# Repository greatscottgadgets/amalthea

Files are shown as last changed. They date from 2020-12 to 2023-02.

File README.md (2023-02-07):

# Amalthea

This repository contains hardware, gateware, and host software sources for Amalthea - an experimental SDR platform.
The main components of the Amalthea hardware are a Lattice ECP5 FPGA, an AT86RF215 radio transceiver, and a Microchip USB3343 USB2.0 PHY (for use with [LUNA](https://luna.readthedocs.io/)).

## Install

 * Clone and install:

```
git clone https://github.com/greatscottgadgets/amalthea
cd amalthea
pip3 install --user --editable '.'
```

 * Add custom block path to `~/.gnuradio/config.conf`:

```
[grc]
local_blocks_path = /path/to/amalthea/amalthea/gnuradio/
```

## Hybrid-SDR

The `amalthea/gnuradio/` directory contains blocks & example flowgraphs for creating mixed FPGA/SDR designs in GNURadio Companion.

### Blocks

 * `hybridsdr.domain.yml` - This defines the `hybridsdr` IO port domain and how connections are made between `hybridsdr` ports.
 * `amalthea_device.block.yml` - This defines the Amalthea Device block, which represents overall device. This block handles gateware elaboration, build, and programming. It will also handle streaming data to/from the host over USB in later versions.
 * `{amalthea_rx,amalthea_demod}.block.yml` - These define some HybridSDR blocks, which represent DSP blocks that run on the FPGA itself. When instantiated, these are added as submodules to the overall Amaranth design.

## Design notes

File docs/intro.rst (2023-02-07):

Introduction
============

HybridSDR is a toolkit for building software-defined radio systems containing a mixture of software running on a general-purpose computer and gateware running an an FPGA. It allows the user to connect signal processing blocks graphically. Then, at runtime, the gateware design is assembled using the flexibility of `Amaranth <https://github.com/amaranth-lang/amaranth>`_. 

Crossings between the gateware and software domains are handled seamlessly. At runtime a custom USB device is built in gateware using `LUNA <https://github.com/greatscottgadgets/luna>`_.

The current proof-of-concept is provided as an out-of-tree module for `GNU Radio <https://www.gnuradio.org>`_, which includes a graphical interface to place & connect signal processing blocks and a large range of existing blocks to use. It targets the ECP5 FPGA on the `Amalthea <https://github.com/greatscottgadgets/amalthea/>`_ open-source radio platform.

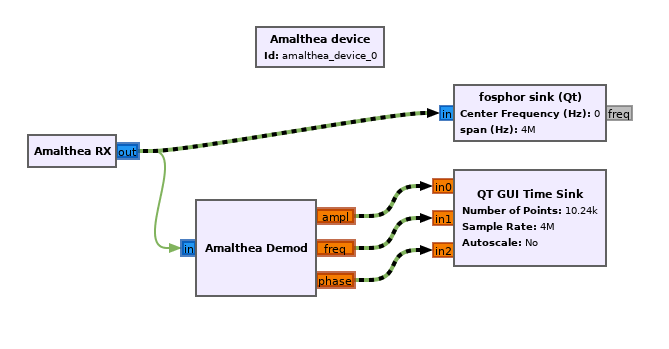
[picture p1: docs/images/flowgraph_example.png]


Above is a screenshot from GNU Radio Companion, showing how the HybridSDR blocks can be used. Green lines represent connections in the gateware domain - these connections and blocks are built into a gateware bitstream at runtime. Green/black striped lines represent seamless connections across USB streams.

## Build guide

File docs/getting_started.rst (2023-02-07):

Getting started
===============

Installation
------------

Clone and install:

::

  git clone https://github.com/greatscottgadgets/amalthea
  cd amalthea
  pip3 install --user --editable '.'

Add custom block path to ~/.gnuradio/config.conf:

::

  [grc]
  local_blocks_path = /path/to/amalthea/amalthea/gnuradio/

Usage
-----

An example flowgraph is provided here: https://github.com/greatscottgadgets/amalthea/blob/master/amalthea/gnuradio/example/hybridsdr.grc

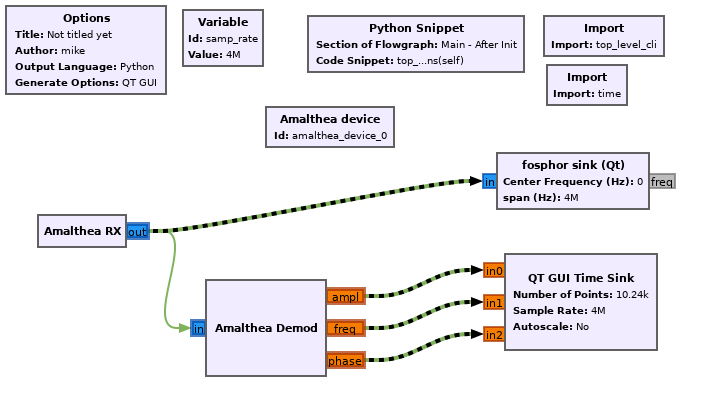
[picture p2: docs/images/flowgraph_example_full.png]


Block details
-------------

Device block
^^^^^^^^^^^^

The HybridSDR device block (`Amalthea device` in this example) represents the external FPGA device and would contain parameters for configuring it/connecting to it. It contains the top-level Amaranth design, the callbacks for registering blocks/connections, and handles the host-side USB streaming when the flowgraph runs.

HybridSDR domain
^^^^^^^^^^^^^^^^

GNU Radio defines the concept of a `sample domain` and allows block inputs/outputs to be placed in a particular domain when they are defined. Here we define a custom `hybridsdr` domain for our FPGA-targeted blocks:

::

  id: hybridsdr
  label: HybridSDR
  color: "#81b35d"
  
  multiple_connections_per_input: false
  multiple_connections_per_output: true
  
  templates:
  -   type: [hybridsdr, hybridsdr]
      connect: self.amalthea_device.connect(("${ source.parent_block.name }", ${ source.key }), ("${ sink.parent_block.name }", ${ sink.key }))
  -   type: [hybridsdr, stream]
      connect: self.amalthea_device.connect_usb(("${ source.parent_block.name }", ${ source.key }), ${ make_port_sig(sink) })
  
This also defines how connections should be made between different domains:
 - Connections between two `hybridsdr` ports are registered with the `Device block`.
 - Connections between `hybridsdr` and `stream` (GNU Radio's standard sample domain) represent a crossing from the FPGA device to the host PC, and have a special callback that will create a seamless USB stream during elaboration.

Gateware blocks
^^^^^^^^^^^^^^^

These are blocks that represent functionality targeted at the FPGA. Here, `Amalthea RX` represents the radio receiver on the Amalthea device and is a source of samples. `Amalthea Demod` represents an Amaranth HDL module implementing amplitude, frequency, and phase demodulation.

Blocks are implemented as standard Amaranth HDL modules, using Amaranth/LUNA stream interfaces for input and output. Blocks are defined and exposed to GNU Radio Companion using standard GNU Radio YAML configuration files. This configuration includes a template for instantiation which registers the block with the `Device block`:

::

  id: amalthea_demod
  label: Amalthea Demod
  category: '[Amalthea]'
  
  templates:
    imports: |-
        import amalthea
    make: |
        self.amalthea_device.add_block("${id}", amalthea.gateware.demod.CORDICDemod(13))

Block inputs and outputs are created within the `hybridsdr` domain:

::

  inputs:
  - domain: hybridsdr
    dtype: complex
    vlen: 1
  
  outputs:
  - domain: hybridsdr
    label: ampl
    dtype: float
    optional: true
  - domain: hybridsdr
    label: freq
    dtype: float
    optional: true
  - domain: hybridsdr
    label: phase
    dtype: float
    optional: true
  
Extras
^^^^^^

GNU Radio doesn't currently have a way for the device block to run code just before the flowgraph starts, so the gateware build/program step is invoked using a `Python Snippet` block in this example:

::

  top_level_cli(self.amalthea_device)
  time.sleep(10)
  self.amalthea_device.finalize_usb_connections(self)

This builds the gatware and programs the Amalthea device, waits for it to start & enumerate, then creates the host-side USB connections to the `stream`-domain blocks.

Other buses
-----------

By default, HybridSDR designs use Amaranth/LUNA stream interfaces between blocks. However, by using the same techniques above to design custom sample domains & connection behaviour, other bus standards can be supported and interconnected.

An example block implementing a pipelined Wishbone interface is included. The domain definition includes a template for inserting an adapter module so that it can interface with the LUNA USB stream interface:

::

  templates:
  -   type: [wishbone, stream]
      connect: |-
          self.${source.parent_block.name}_stream = amalthea.gateware.wishbone_example.StreamAdapter(self.${source.parent_block.name})
          self.amalthea_device.add_block("${source.parent_block.name}_stream", self.${source.parent_block.name}_stream)
          self.amalthea_device.connect_usb(("${ source.parent_block.name }_stream", ${ source.key }), ${ make_port_sig(sink) })

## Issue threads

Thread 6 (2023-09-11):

What happened to this project?

Hoernchen, 2023-09-11:
I have just discovered this and it kinda looks like a great fgpa/atrf dev board - after browsing twitter for a bit it looks like at least iq rx streaming to GR/fossphor was actually validated with real hardware, are there any known issues? I guess this project, just like so many other projects, just stalled due to part shortages?

mossmann, 2023-09-12:
The project is still progressing slowly. The current incarnation of hardware is a small add-on for Cynthion: https://github.com/greatscottgadgets/amalthea-hardware

@mndza has been working on DSP gateware here: https://github.com/mndza/dsp_sandbox

Closed 2023-11-06.

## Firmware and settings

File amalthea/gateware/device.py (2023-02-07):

#!/usr/bin/env python3
# pylint: disable=no-member

import os
import sys
import logging
import time
import usb1
import xdg.BaseDirectory

import numpy as np

from amaranth                        import *
from amaranth.lib.fifo               import AsyncFIFO
from amaranth.build.run              import LocalBuildProducts

from usb_protocol.types              import USBRequestType
from usb_protocol.emitters           import DeviceDescriptorCollection

from luna                            import top_level_cli
from luna.usb2                       import *
from luna.gateware.usb.usb2.request  import USBRequestHandler
from luna.gateware.platform          import get_appropriate_platform

from .radio                          import IQReceiver, RadioSPI
from .demod                          import CORDICDemod
from .stream                         import IQStream, SampleStream, StreamCombiner

from ..gnuradio.amaltheasource import AmaltheaSource


VENDOR_ID  = 0x16d0
PRODUCT_ID = 0x0f3b

BULK_ENDPOINT_NUMBER = 1
MAX_BULK_PACKET_SIZE = 64 if os.getenv('LUNA_FULL_ONLY') else 512

class RadioSPIRequestHandler(USBRequestHandler):
    """ Read/write radio SPI registers. """

    REQUEST_WRITE_REG = 0

    def __init__(self):
        super(RadioSPIRequestHandler, self).__init__()
        self.spi_start       = Signal()
        self.spi_busy        = Signal()
        self.spi_address     = Signal(14)
        self.spi_write       = Signal()
        self.spi_write_value = Signal(8)

    def elaborate(self, platform):
        m = Module()

        interface         = self.interface
        setup             = self.interface.setup

        m.d.comb += self.spi_write.eq(1) # Only support writes for now
        m.d.sync += self.spi_start.eq(0)

        with m.If(setup.type == USBRequestType.VENDOR):
            with m.FSM():
                with m.State('IDLE'):
                    with m.If(setup.received):
                        with m.Switch(setup.request):
                            with m.Case(self.REQUEST_WRITE_REG):
                                m.d.sync += [
                                    self.spi_address.eq(setup.index[:14]),
                                    self.spi_write_value.eq(setup.value[:8]),
                                    self.spi_start.eq(1),
                                ],
                                m.next = 'WRITE_REG'

                            with m.Default():
                                m.next = 'UNHANDLED'

                with m.State('WRITE_REG'):
                    # Once the receive is complete, respond with an ACK.
                    with m.If(interface.rx_ready_for_response):
                        m.d.comb += interface.handshakes_out.ack.eq(1)

                    # If we reach the status stage, send a ZLP.
                    with m.If(interface.status_requested):
                        m.d.comb += self.send_zlp()
                        m.next = 'IDLE'


                with m.State('UNHANDLED'):

                    #
                    # Stall unhandled requests.
                    #
                    with m.If(interface.status_requested | interface.data_requested):
                        m.d.comb += interface.handshakes_out.stall.eq(1)
                        m.next = 'IDLE'

                return m


class Device(Elaboratable):
    """ Amalthea device. """

    def __init__(self):
        self._rx = IQReceiver();
        self._blocks = {}
        self._usb_outputs = []
        self._connections = []
        self._usb_connections = []

    def get_rx(self):
        return self._rx

    def add_block(self, block_id, block):
        self._blocks[block_id] = block
        return block

    def connect(self, source, sink):
        print(f"connect {source} {sink}")
        source_id, source_output = source
        sink_id, sink_input = sink

        source_block = self._blocks[source_id]
        sink_block   = self._blocks[sink_id]
        self._connections.append(sink_block.input.stream_eq(source_block.outputs[source_output]))

    def connect_usb(self, source, sink):
        print(f"connect_usb {source}")
        block_id, output_id = source
        self._usb_outputs.append(self._blocks[block_id].outputs[output_id])
        self._usb_connections.append((len(self._usb_outputs)-1, sink))

    def flash(self):
        platform = get_appropriate_platform()
        plan = platform.build(self, do_build=False)
        cache_dir = os.path.join(
            xdg.BaseDirectory.save_cache_path('amalthea'),
            'build',
            plan.digest().hex()
        )
        if os.path.exists(cache_dir):
            products = LocalBuildProducts(cache_dir)
        else:
            products = plan.execute_local(cache_dir)

        platform.toolchain_program(products, name="top")

    def finalize_usb_connections(self, tb):
        def to_np_type(output):
            if isinstance(output, IQStream):
                return np.complex64
            if isinstance(output, SampleStream):
                return np.float32
            raise TypeError("Unknown stream type")

        signature = list(map(to_np_type, self._usb_outputs))
        self._usb_source = AmaltheaSource(4e6, 2.45e9, signature)
        for conn in self._usb_connections:
            tb.connect((self._usb_source, conn[0]), conn[1])


    def create_descriptors(self):
        """ Create the descriptors we want to use for our device. """

        descriptors = DeviceDescriptorCollection()

        #
        # We'll add the major components of the descriptors we we want.
        # The collection we build here will be necessary to create a standard endpoint.
        #

        # We'll need a device descriptor...
        with descriptors.DeviceDescriptor() as d:
            d.idVendor           = VENDOR_ID
            d.idProduct          = PRODUCT_ID

            d.iManufacturer      = "GSG"
            d.iProduct           = "Amalthea receiver"
            d.iSerialNumber      = "no serial"

            d.bNumConfigurations = 1


        # ... and a description of the USB configuration we'll provide.
        with descriptors.ConfigurationDescriptor() as c:

            with c.InterfaceDescriptor() as i:
                i.bInterfaceNumber = 0

                with i.EndpointDescriptor() as e:
                    e.bEndpointAddress = 0x80 | BULK_ENDPOINT_NUMBER
                    e.wMaxPacketSize   = MAX_BULK_PACKET_SIZE


        return descriptors


    def elaborate(self, platform):
        m = Module()

        # Generate our domain clocks/resets.
        m.submodules.car = platform.clock_domain_generator()

        # Create our USB device interface...
        ulpi = platform.request("host_phy")
        m.submodules.usb = usb = USBDevice(bus=ulpi)

        # Add our standard control endpoint to the device.
        descriptors = self.create_descriptors()
        control_ep = usb.add_standard_control_endpoint(descriptors)

        # Add our vendor request handler
        handler = DomainRenamer("usb")(RadioSPIRequestHandler())
        control_ep.add_request_handler(handler)

        radio = platform.request("radio")
        m.d.comb += radio.rst.eq(0)

        # Setup the radio SPI interface.
        radio_spi = DomainRenamer("usb")(RadioSPI(clk_freq=60e6))
        m.submodules += radio_spi

        m.d.comb += [
            # Output pins
            radio.sel              .eq(radio_spi.sel),
            radio.clk              .eq(radio_spi.clk),
            radio.copi             .eq(radio_spi.copi),

            # Input pins
            radio_spi.cipo         .eq(radio.cipo),

            # Vendor request handler connections
            radio_spi.start        .eq(handler.spi_start),
            handler.spi_busy       .eq(radio_spi.busy),
            radio_spi.address      .eq(handler.spi_address),
            radio_spi.write        .eq(handler.spi_write),
            radio_spi.write_value  .eq(handler.spi_write_value),
        ]

        # Create radio clock domain
        m.domains.radio = ClockDomain()
        m.d.comb += [
            ClockSignal("radio").eq(radio.rxclk),
            ResetSignal("radio").eq(ResetSignal()),
        ]

        # Get IQ samples.
        iq_rx = self.get_rx()
        m.d.comb += iq_rx.rxd.eq(radio.rxd24)

        #
        m.submodules += map(DomainRenamer("radio"), self._blocks.values())
        m.d.comb += self._connections

        combined = StreamCombiner(
            streams=self._usb_outputs,
            domain="radio",
        )
        m.submodules += combined

        payload = combined.output.payload
        usb_data = Cat(
            # Pad each 13-bit value to 16-bits for now.
            payload.word_select(i, 13).shift_left(3) for i in range(int(len(payload)/13))
        )
        assert (len(usb_data) % 8) == 0, f"{len(usb_data)}"


        # Add a stream endpoint to our device.
        stream_ep = USBMultibyteStreamInEndpoint(
            byte_width=int(len(usb_data)/8),
            endpoint_number=BULK_ENDPOINT_NUMBER,
            max_packet_size=MAX_BULK_PACKET_SIZE
        )
        usb.add_endpoint(stream_ep)

        # Connect our device as a high speed device by default.
        m.d.comb += [
            usb.connect          .eq(1),
            usb.full_speed_only  .eq(1 if os.getenv('LUNA_FULL_ONLY') else 0),
        ]

        # Connect up the IQ receiver to the USB stream, via a small FIFO.
        fifo  = AsyncFIFO(width=len(usb_data), depth=128, r_domain="usb", w_domain="radio")
        m.submodules += fifo
        m.d.comb += [
            combined.output.ready      .eq(fifo.w_rdy),
            fifo.w_en                  .eq(combined.output.valid),
            fifo.w_data                .eq(usb_data),
            fifo.r_en                  .eq(stream_ep.stream.ready),
            stream_ep.stream.valid     .eq(fifo.r_rdy),
            stream_ep.stream.payload   .eq(fifo.r_data),
            stream_ep.stream.last      .eq(0),
        ]

        # Debug LEDs.
        led0 = platform.request("led", 0)
        m.d.radio += led0.eq(iq_rx.outputs[0].valid)
        led1 = platform.request("led", 1)
        m.d.usb += led1.eq(stream_ep.stream.valid)
        led2 = platform.request("led", 2)
        m.d.radio += led2.eq(fifo.w_rdy)


        return m


if __name__ == "__main__":
    device = top_level_cli(Device)

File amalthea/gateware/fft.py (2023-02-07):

from amaranth import *
from amaranth.hdl.dsl import _ModuleBuilderSubmodules
from amaranth.sim import Simulator, Settle
from .types.complex import Complex, ComplexConst
from .types.fixed_point import Q
from .util import variable_rotate_left
import cmath
import math
import numpy as np
import unittest


class FFT(Elaboratable):
    def __init__(self, fft_size, sample_shape):
        self.fft_size = fft_size
        levels = math.log2(fft_size)
        assert levels.is_integer()
        self.level_count = int(levels)
        self.butterfly_count = int(fft_size / 2)

        self.sample_shape = sample_shape
        self.internal_shape = Q(sample_shape.integer_bits + self.level_count, sample_shape.fraction_bits)
        self.twiddle_factor_shape = Q(1, len(self.internal_shape)-1)

        self.mem = Memory(width=len(Complex(shape=self.internal_shape).value()), depth=fft_size)
        self.read_addr = Signal(range(fft_size))
        self.read_data = Signal(self.mem.width)

        self.start = Signal()
        self.done = Signal()

        self._addr_gen = AddressGenerator(self.level_count, self.butterfly_count)
        self._butterfly = Butterfly(self.internal_shape, self.twiddle_factor_shape)

    def elaborate(self, platform):
        m = Module()

        next_address = Signal()
        reset = Signal()

        m.submodules.addr_gen = ResetInserter(reset)(
            EnableInserter(next_address)(
                self._addr_gen
            )
        )

        m.submodules.butterfly = self._butterfly
        m.submodules.twiddle_factors = twiddle_factors = TwiddleFactors(self.fft_size, self.twiddle_factor_shape)

        m.submodules.read_a = read_a = self.mem.read_port(transparent=False)
        m.submodules.read_b = read_b = self.mem.read_port(transparent=False)
        m.submodules.write_a = write_a = self.mem.write_port()
        m.submodules.write_b = write_b = self.mem.write_port()
        m.d.comb += [
            # Addresses
            read_a.addr.eq(Mux(self.done, self.read_addr, self._addr_gen.addr_a)),
            read_b.addr.eq(self._addr_gen.addr_b),
            write_a.addr.eq(self._addr_gen.addr_a),
            write_b.addr.eq(self._addr_gen.addr_b),
            twiddle_factors.addr.eq(self._addr_gen.addr_twiddle),

            # Data reads
            self._butterfly.in_a.value().eq(read_a.data),
            self._butterfly.in_b.value().eq(read_b.data),
            self._butterfly.twiddle_factor.eq(twiddle_factors.out),
            self.read_data.eq(read_a.data),

            # Data writes
            write_a.data.eq(self._butterfly.out_a.value()),
            write_b.data.eq(self._butterfly.out_b.value()),
        ]
        with m.FSM() as fsm:
            with m.State("IDLE"):
                m.d.comb += [
                    reset.eq(1),
                    self.done.eq(1),
                ]
                with m.If(self.start):
                    m.next = "READ"

            with m.State("READ"):
                m.d.comb += [
                    read_a.en.eq(1),
                    read_b.en.eq(1),
                ]
                m.next = "WAIT"
                with m.If(self._addr_gen.done):
                    m.next = "IDLE"

            with m.State("WAIT"):
                m.next = "WRITE"

            with m.State("WRITE"):
                m.d.comb += [
                    write_a.en.eq(1),
                    write_b.en.eq(1),
                    next_address.eq(1),
                ]
                m.next = "READ"


        return m


class AddressGenerator(Elaboratable):
    def __init__(self, level_count, butterfly_count):
        self.level_count = level_count
        self.butterfly_count = butterfly_count

        self.done         = Signal()
        self.addr_a       = Signal(range(butterfly_count*2))
        self.addr_b       = Signal(range(butterfly_count*2))
        self.addr_twiddle = Signal(range(butterfly_count))

    def elaborate(self, platform):
        m = Module()

        level        = Signal(range(self.level_count))
        index        = Signal(range(self.butterfly_count))
        twiddle_mask = Signal.like(index)

        final_level = (level == self.level_count - 1)
        next_level  = (index == self.butterfly_count - 1)


        with m.If(next_level):
            m.d.sync += [
                level.eq(level + 1),
                index.eq(0),
                twiddle_mask.eq(Cat(twiddle_mask[1:], 1)),
            ]
            with m.If(final_level):
                m.d.sync += self.done.eq(1)

        with m.Else():
            m.d.sync += [
                index.eq(index + 1),
            ]

        addr_a = (index << 1)
        addr_b = addr_a + 1

        addr_a = variable_rotate_left(addr_a[:self.level_count], level)
        addr_b = variable_rotate_left(addr_b[:self.level_count], level)

        m.d.comb += [
            self.addr_a.eq(addr_a),
            self.addr_b.eq(addr_b),
            self.addr_twiddle.eq(index & twiddle_mask),
        ]

        return m


class Butterfly(Elaboratable):
    def __init__(self, sample_shape, twiddle_factor_shape):
        self.sample_shape   = sample_shape
        self.in_a           = Complex(shape=sample_shape)
        self.in_b           = Complex(shape=sample_shape)
        self.out_a          = Complex(shape=sample_shape)
        self.out_b          = Complex(shape=sample_shape)
        self.twiddle_factor = Complex(shape=twiddle_factor_shape)

    def elaborate(self, platform):
        m = Module()

        a = self.in_a
        b = self.in_b * self.twiddle_factor
        b = b.reshape(self.sample_shape)
        m.d.comb += [
            self.out_a.eq((a + b).reshape(self.sample_shape)),
            self.out_b.eq((a - b).reshape(self.sample_shape)),
        ]

        return m


class TwiddleFactors(Elaboratable):
    def __init__(self, fft_size, sample_shape):
        self.fft_size = fft_size

        tf_count = int(fft_size/2)

        def tf(k):
            tf = cmath.exp(-1j * math.tau * k / fft_size)
            m = 2**sample_shape.fraction_bits - 1
            return (round(tf.real*m), round(tf.imag*m))

        twiddle_factors = [tf(k) for k in range(tf_count)]
        tf_real = [x[0] for x in twiddle_factors]
        tf_imag = [x[1] for x in twiddle_factors]
        self.mem_real = Memory(width=len(sample_shape), depth=len(twiddle_factors), init=tf_real)
        self.mem_imag = Memory(width=len(sample_shape), depth=len(twiddle_factors), init=tf_imag)
        self.out   = Complex(shape=sample_shape)
        self.addr  = Signal(range(tf_count))


    def elaborate(self, platform):
        m = Module()
        m.submodules.rd_real = rd_real = self.mem_real.read_port()
        m.submodules.rd_imag = rd_imag = self.mem_imag.read_port()
        m.d.comb += [
            rd_real.addr.eq(self.addr),
            rd_imag.addr.eq(self.addr),
            self.out.real.eq(rd_real.data),
            self.out.imag.eq(rd_imag.data),
        ]
        return m
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

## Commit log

2020-03-25 Start with LUNA
    [debug_control_connections.sch, fpga_configuration.sch, host_side.sch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]
2020-03-25 Bulk rename
    [amalthea_rev0.kicad_pcb, amalthea_rev0.sch, debug_control_connections.sch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]
2020-03-30 Update license
    [amalthea_rev0.sch, debug_control_connections.sch, fpga_configuration.sch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]
2020-03-30 Remove target PHY
    [amalthea_rev0.sch, target_side.sch]
2020-03-30 Add AT86RF215 & some schematic hookup
    [target_side.sch]
2020-03-30 More tidying
    [amalthea_rev0.kicad_pcb]
2020-03-31 Rough out LVDS
    [amalthea_rev0.kicad_pcb, amalthea_rev0.sch, target_side.sch]
2020-04-06 Add baluns, matching, TXCO, decoupling
    [amalthea_rev0.kicad_pcb, amalthea_rev0.sch, target_side.sch]
2020-04-07 Do a bunch of placement
    [amalthea_rev0.kicad_pcb, amalthea_rev0.sch, target_side.sch]
2020-04-08 Start re-arranging user IO
    [amalthea_rev0.kicad_pcb, amalthea_rev0.sch, host_side.sch]
2020-04-08 Switch to 3V3 for RAM, remove 1V8 rail
    [amalthea_rev0.kicad_pcb, fpga_configuration.sch, power_supplies.sch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]
2020-04-08 Route LVDS user IO
    [amalthea_rev0.kicad_pcb, amalthea_rev0.sch, debug_control_connections.sch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]
2020-04-09 Tidy up decoupling & fix a bunch of DRC errors
    [amalthea_rev0.kicad_pcb, power_supplies.sch]
2020-04-09 Route most of the 'RF215
    [amalthea_rev0.kicad_pcb, target_side.sch]
2020-04-13 Route RF bit, finish io0/1, DRC fixups
    [amalthea_rev0.kicad_pcb]
2020-04-14 Fix error in balun footprint & re-route
    [amalthea_rev0.kicad_pcb]
2020-04-14 Fix TCR2EE footprint
    [amalthea_rev0.kicad_pcb, power_supplies.sch]
2020-04-14 Route/NC remaining target signals, ERC & schematic cleanup
    [amalthea_rev0.kicad_pcb, amalthea_rev0.sch, debug_control_connections.sch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]
2020-04-14 Extend RF-side ground pour
    [amalthea_rev0.kicad_pcb]
2020-04-14 Hide component references
    [amalthea_rev0.kicad_pcb]
2020-04-14 Tidy up component values
    [fpga_configuration.sch, host_side.sch, power_supplies.sch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]
2020-04-14 Tidy up RF09_x routing
    [amalthea_rev0.kicad_pcb]
2020-04-14 Tidy up silk
    [amalthea_rev0.kicad_pcb]
2020-04-14 Widen RF diff traces
    [amalthea_rev0.kicad_pcb]
2020-04-14 Rejig user IO
    [amalthea_rev0.kicad_pcb, amalthea_rev0.sch, host_side.sch]
2020-04-19 Pick part numbers for BOM
    [amalthea_rev0.sch, fpga_configuration.sch, host_side.sch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]
2020-04-19 Swap TCXO for one available on Mouser
    [target_side.sch]
2020-04-19 Fix TCR2EE11 MPN
    [power_supplies.sch]
2020-04-20 Swap JTAG connector part
    [fpga_configuration.sch]
2020-04-23 Fix meander
    [amalthea_rev0-B_Cu.gbl, amalthea_rev0-B_Mask.gbs, amalthea_rev0-B_Paste.gbp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]
2020-04-27 Add gateware for radio config over SPI
2020-05-08 gateware.radio: drop SPI freq for interactive test & add sanity asserts
2020-05-08 interactive-test: add radio test-case
2020-05-11 interactive-test: support radio SPI writes
2020-05-15 receiver: add vendor request to write radio SPI registers
2020-05-16 receiver: receive some samples!
2020-05-29 receiver: make it work
    * Only emit a full IQ sample when possible & use Serializer to prep it
    for USB FIFO.
    * Add loop-back mode & TX counter for testing.
2020-07-03 hardware: adopt OSHWA convention for SPI signal names
    https://www.oshwa.org/a-resolution-to-redefine-spi-signal-names
    [amalthea_rev0.kicad_pcb, amalthea_rev0.sch, right_side_indicators.sch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]
2020-07-28 gateware: swap serializer endianness to tidy up `iq_sample` signal
    [util.py]
2020-07-28 gateware: change i/q samples to signed
2020-10-10 gateware: receiver -> device
2020-10-10 gateware.device: Drop old demo code.
2020-10-11 initial flowgraph build support
2020-10-12 gateware.device: drop old TX loopback test code
2020-10-15 gateware: add missing stream.py
    [stream.py]
2020-10-15 gateware.demod: fix overflow due to CORDIC gain
    [demod.py]
2020-10-18 Working block creation/connection & device building from GRC
2020-11-14 gateware.device: fix stream connections for latest LUNA
    See LUNA @ cd40642 for more detail.
    [device.py]
2021-02-17 Poll for device connect after programming
2021-05-31 gateware: convert Complex to use FixedPointValue
    [fft.py]
2021-06-26 gateware.fft: update classes to use fixed-point shapes
    [fft.py]
2021-06-26 gateware.fft: fix twiddle address generation
    [fft.py]
2021-06-26 gateware.fft: fix twiddle factors
    The previous TFs matched those given in the paper
    "The Fast Fourier Transform in Hardware: A Tutorial Based on an FPGA Implementation"
    but the overall FFT results were incorrect (mirrored around the real
    axis).
    This changes the TF equation to match other literature and gives the
    correct FFT result when compared to numpy.fft.
    [fft.py]
2021-06-26 gateware.fft: fix Butterfly sample shapes
    [fft.py]
2023-02-07 Rename nMigen to Amaranth HDL
    [amalthea_rev0.kicad_pcb]
2023-02-07 Update example for newer GNURadio versions
    A priority value had to be added to run the flowgraph, other changes came from loading & re-saving it.
